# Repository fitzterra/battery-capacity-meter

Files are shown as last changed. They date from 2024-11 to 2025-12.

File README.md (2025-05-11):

Battery Capacity Meter
======================

**Table of Content**

1. [Introduction](#introduction)
2. [Components and software Stack](#components-and-software-stack)
3. [Project Layout](#project-layout)
4. [Firmware Development](#firmware-development)
	1. [Dev environment setup](#dev-environment-setup)
	2. [Flashing MicroPython](#flashing-micropython)
	3. [Submodules](#submodules)
	4. [Building and uploading firmware](#building-and-uploading-firmware)
		1. [Building](#building)
		2. [Uploading](#uploading)
	5. [Building docs](#building-docs)
5. [Documentation](#documentation)

Introduction
------------

This is a project to build something that can measure the capacity of
Lithium-Ion batteries, specifically 18650 cells, but not limited to those.

In order to fairly accurately measure the cell capacity, one has to do a full
discharge of the cell, and measure the energy used during the recharge. Or
alternatively, charge a fully discharged cell, measuring the energy used to get
battery to full capacity.

To get fairly accurate measurements from these techniques are more difficult
that it sounds due to some factors such as:

* Fully charged, or fully discharged are relative states. Unless whatever is
    used to accurately measure fully dis/charged state, there could be large
    variances.
* Unless the dis/charge cycle is done at a very high current rate, it could
    take a long time to fully dis/charge a cell of even a nominal capacity.
* Using large dis/charge currents is not the best way to measure capacity and
    may be more damaging than it needs to be.

To solve this, this meter has these features:

* Allows multiple (up to 4) batteries to be measured independently and
    concurrently.
* Uses known components and calibration to ensure that the fully dis/charged
    states are as close as the same at all times as possible.
* Does not use very large dis/charge currents to do the measurements.
* All dis/charge telemetry are streamed as MQTT data points to allow these to be
    captured in a separate system or database for further analysis - The
    **Battery Capacity Meter UI** project is a UI that evaluates these data
    points and record history and state for a collection of batteries.
* Each battery being measured is given, and expected to have, a unique ID that
    can be used to identify that battery in the telemetry as well as for
    keeping history.
* Allows singe charging, single discharging or full measurement cycles to be
    run per battery.
* A full measurement cycle will first charge the battery fully, then run 2
    (configurable) discharge and then charge cycles.

Components and software Stack
-----------------------------

* ESP32
* Micropython
* ADC ???
* OLED
* Encoder
* TP4056 Breakout
* KiCAD
* Black
* Pylint

Project Layout
--------------

The project contains the hardware sources (schematics, PCB, etc.), firmware
sources, docs, etc. The base structure is:

    ├── doc
    │   ├── design              - Firmware state diagrams, etc.
    │   ├── Electronics         - Schematics, etc in SVG or image format
    │   └── firmware-api        - Firmware auto generated docs - not versioned
    ├── Electronics
    │   └── BatCapMeter         - KiCad project for BC Meter and Controller
    └── Firmware
        ├── ScreenDesign        - Screen design images
        ├── src                 - Firmware source code dir
        │   ├── firmware        - Firmware build dir - not versioned
        │   ├── lib             - Various source libs
        │   ├── micropython_binary - MP binary will be downloaded here - not versioned
        │   ├── pydoctor_templates - Templates for auto HTML api doc building
        │   ├── runtime_conf    - Runtime config before uploading new firmware
        │   ├── testing         - Testing and demos for various libs - NOT testcases
        │   └── ui              - OLED+Rotary Encode UI library
        └── submodules          - All submodules used by the firmware
            ├── micropython-ads1x15
            ├── micropython-mqtt
            ├── micropython-stubs
            ├── micropython-tools
            ├── ssd1306_mp
            ├── ubutton
            └── uencoder

Firmware Development
--------------------

The BCM firmware is in the `Firmware/src` dir and this is the root dir for
development.

There are a number of moving parts to getting the development done, so as much
as possible is set up in a `Makefile` to help with this.

After setting the development environment up (see below), run `make help` to
see what make commands are available.

### Dev environment setup

The development environment also relies on a Python virtual environment to be
available.

The first thing to do is to ensure you set a `venv` up and make sure it is
activated when in the `Firmware/src` dir.

A very easy way to do this is by using [direnv]. This is normally very easy to
install in Linux and MacOS via your package manager or [Homebrew]. An `.envrc`
file for [direnv] is provided in `Firmware/.envrc`. Once you change into this
dir, you will be asked to allow this RC file, and it will set up an Python 3
virtual environment, as well as some other environment variables needed by the
`Makefile`.

You may have to adjust the `DEVICE_PORT` value in this `.envrc` to match the
device your board presents if it is not `/dev/ttyACM0` as the ESP32-S2 does on
Linux. Try `make detect-device` once your environment is set up and the device
is connected - YMMV.

If not using [direnv], make sure you have your own python virtual environment
set up and that the environment variables as in `Firmware/.envrc` are exported
when running any `make` command.

With all this done, run `make dev-env` to install all required Python packages
needed for firmware dev.

### Flashing MicroPython

The Micropython binary to flash to the ESP32 device is defined in the
`MCU_CONF` file.  
Please update this file is required, but this project is built around the Wemos
S2 Mini and all is set up for that device.

The version of the MP binary can be updated though. Look the `MP_DOWNLOAD_SITE`
config value for the download URL. Updated versions may be found there.

In order to get the S2 Mini into flash mode, press and delete both onboard
buttons at the same time. This is needed for all of the binary flash commands
(not needed for firmware flashing as described below).

If this is the first time flashing this device, then the flash first needs to
be erased with `make erase-flash`.

To flash the MP binary, do `make flash-bin`. If the MP binary is not already
downloaded, it will be downloaded from the download URL in the `MCU_CONF` file.

After flashing, reset the device by pressing the reset button.

Now the firmware can be flashed after making sure the submodules are set up.

### Submodules

The firmware uses a number of submodules for various bit of functionality.
These are `git submodules` and you must make sure all submodules have been
cloned. Do this with:

    git submodules sync
    git submodules udate --init

All submodules are cloned as their own repos under `Firmware/submodules`.

I order to include any parts of these submodules in the source, we simply
create symlinks from the submodule to the name we want for it in the source.
For example here are submodules symlinked in the `src/lib` dir:

    ads1x15.py -> ../../submodules/micropython-ads1x15/ads1x15.py
    led.py -> ../../submodules/micropython-tools/led.py
    mqtt_as.py -> ../../submodules/micropython-mqtt/mqtt_as/__init__.py
    ssd1306.py -> ../../submodules/ssd1306_mp/ssd1306.py
    ubutton.py -> ../../submodules/ubutton/ubutton.py
    uencoder.py -> ../../submodules/uencoder/uencoder.py

### Building and uploading firmware

After making sure the submodules are set up as described above, the firmware
can be built and uploaded as described below.

#### Building
This is done with the simple command: `make build`

The way this works is as follows:

* All the Python source files that will make up the final firmware are defined
    in the `MPY_SRC` list in the `Makefile`. If new files are added or others
    removed, this list **MUST** be updated.
* From this list, all source files will first be cross compiled in order to
    speed up runtime.
* As `make` is supposed to do, only changed sources files will be compiled if
    they have not been compiled before.
* All compiled files (`.mpy`) are placed in the `firmware` dir (which will be
    created if it does not exist, and is not versioned), using the same files
    structure as in the `src` dir.
* After this, `firmware` dir is now ready to be uploaded to the device.

#### Uploading

Once the firmware has been built, it can be uploaded.

This is done with `make upload`. Note that the upload target will also first
build any outdated firmware if run directly with having done a `make build`
first.

The firmware allows certain runtime configurations to be made via the OLED +
Encoder UI. These are effectively changes to any default config values and are
then saved in new runtime config files on the device.

In order to make sure **ONLY** the files in the firmware as built will be
placed on the device with the next firmware upload, the upload is a type of
file sync operation where any files not appearing in the built firmware folder,
are deleted from the device, while changed files are uploaded.

This sync operation also makes the uploads faster because only new and changed
compiled files are uploaded.

The problem is with the runtime configs. Since these are not part of the built
firmware, they are also deleted. This is not ideal while developing because
then any runtime config changes needs to be done after every firmware upload.

For this reason the `Makefile` has the `runtime-cfg-backup` target that will
look for any of these runtime config files on the device and copy them to
`runtime_conf/backup`.

The `upload` target has the `runtime-cfg-backup` target as dependency which
will then always first backup any runtime config files before doing the upload
sync. Afterwards, all runtime backups will then be copied back to the device.

To quickly get a REPL after changes were made to any files and an update is
needed, this flow is very useful:

    make upload repl

which will make a new build, backup runtime configs, upload only the changes,
restore runtime config and immediately connect to the device and start the REPL.

### Building docs

The source is extensively documented using Python docstrings. This allows
automatically generating a complete set of source and app documentation using
[pydoctor]

The [pydoctor] main setup is in the `pydoctor.ini` file with some additional
setup in the `docs` target in the `Makefile`.

To build the documentation, run `make docs` - this will show any doc errors,
and build the final static HTML docs in `doc/firmware-api/` from the top level
dir. In this dir will be an `index.html` file that can be opened directly in a
browser.

There is also a CI job for GitLab that will build the docs and make them
available as GitLab pages for the repo. See [Documentation](#Documentation)
below for more.

Documentation
-------------

The application is written in Micropython and the full app docs are available
[here](http://pages.gaul.za/gaulnet/battery-capacity-meter/)

<!-- links -->
[direnv]: https://github.com/direnv/direnv
[Homebrew]: https://brew.sh/
[pydoctor]: https://pydoctor.readthedocs.io

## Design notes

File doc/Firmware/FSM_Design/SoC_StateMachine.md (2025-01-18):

SoC Measure State Machine
=========================

Below is a [state diagram] that governs the [FSM] for measuring SoC for a given
Battery Controller.

```mermaid
---
title: SoC Measurement State Diagram
---

stateDiagram-v2
    direction TB

    classDef error fill:#a44,color:white,font-weight:bold,stroke-width:2px,stroke:#700
    classDef charging fill:#4a4,color:white,font-weight:bold,stroke-width:2px,stroke:#070
    classDef discharging fill:#d50,color:white,font-weight:bold,stroke-width:2px,stroke:#a20
    classDef resting fill:#036,color:white,font-weight:bold,stroke-width:2px,stroke:#059
    classDef canceled fill:#770,color:white,font-weight:bold,stroke-width:2px,stroke:#330
    classDef completed fill:#336,color:white,font-weight:bold,stroke-width:2px,stroke:#559

    %% Possible states and actions to perform when
    %% Transitioning to that state.
    READY: Ready
    CHARGING_1ST: Initial Charge
    note left of CHARGING_1ST
        num_cycles = 0
    end note
    CHARGING: Charging
    REST_CH: Rest post charge
    note right of REST_CH
        num_cycles++
    end note
    DISCHARGING: Discharging
    REST_DCH: Rest post discharge
    COMPLETE: SoC Complete
    CANCEL: SoC Canceled
    ERROR: Error

    class ERROR error
    class CHARGING, CHARGING_1ST charging
    class DISCHARGING discharging
    class REST_CH, REST_DCH resting
    class CANCEL canceled
    class COMPLETE completed

    [*] --> READY

    %% Unexpected Battery Controller state goes to error
    READY --> ERROR: unexpected BC state
    CHARGING_1ST --> ERROR: unexpected BC state
    CHARGING --> ERROR: unexpected BC state
    DISCHARGING --> ERROR: unexpected BC state
    REST_CH --> ERROR: unexpected BC state
    REST_DCH --> ERROR: unexpected BC state

    %% Cancel at any stage
    CHARGING_1ST --> CANCEL: cancel
    CHARGING --> CANCEL: cancel
    DISCHARGING --> CANCEL: cancel
    REST_CH --> CANCEL: cancel
    REST_DCH --> CANCEL: cancel

    %% Manual error reset
    ERROR --> [*]

    %% Start SoC measurement
    READY --> CHARGING_1ST: charge

    %% Rest after 1st charge
    CHARGING_1ST --> REST_CH: charge complete

    %% Starting the cycle

    %% Discharge
    REST_CH --> DISCHARGING: discharge

    %% Fully discharging
    DISCHARGING --> REST_DCH: discharge complete

    %% Charge cycle
    REST_DCH --> CHARGING: charge

    state CycleComplete <<choice>>

    %% Charge complete
    CHARGING --> CycleComplete: charge complete
    CycleComplete -->  REST_CH: num_cycles < max_cycles, charge complete
    CycleComplete -->  COMPLETE: num_cycles == max_cycles, cycle complete

    %% Exit after SoC Complete or Canceled
    COMPLETE --> [*]
    CANCEL --> [*]
```

See the [code] and [api-docs] for more details.

This state diagram was also converted to a [DrawIO] diagram and saved a [PNG].

<!-- Links -->
[state diagram]: https://mermaid.js.org/syntax/stateDiagram.html
[FSM]: https://en.wikipedia.org/wiki/Finite-state_machine
[code]: ./Firmware/src/lib/statemachines.py
[api-docs]: doc/firmware-api/src.lib.bat_controller.StateMachine.html
[DrawIO]: https://app.diagrams.net/
[PNG]: doc/design/SoC_StateMachine.drawio.png
[vim-modeline]: # ( vim: set nofoldenable: )

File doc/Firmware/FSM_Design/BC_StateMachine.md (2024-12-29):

Battery Controller State Machine
================================

Below is a [state diagram] that governs the [FSM] for controlling and monitoring
the Battery Controller.

```mermaid
---
title: Battery Control and Monitor
---

stateDiagram-v2
    direction TB

    classDef yanked fill:#a44,color:white,font-weight:bold,stroke-width:2px,stroke:#700
    classDef charged fill:#4a4,color:white,font-weight:bold,stroke-width:2px,stroke:#070
    classDef discharged fill:#d50,color:white,font-weight:bold,stroke-width:2px,stroke:#a20
    classDef paused fill:#660,color:white,font-weight:bold,stroke-width:2px,stroke:#880
    classDef currentflow fill:#036,color:white,font-weight:bold,stroke-width:2px,stroke:#059
    classDef ready fill:#336,color:white,font-weight:bold,stroke-width:2px,stroke:#559
    
    %% Possible states and actions to perform when
    %% Transitioning to that state.
    DISABLED: Disabled
    note right of DISABLED
        Monitors disabled
        Ch and Dch Off
    end note
    NOBAT: No Battery
    note right of NOBAT
        Ch and Dch Stop
        Reset Bat ID
    end note
    BAT_NOID: Battery, No ID
    note right of BAT_NOID
        Gen Bat ID
    end note
    GET_ID: Input Bat ID
    BAT_ID: Battery + ID
    note right of BAT_ID
        Reset monitors
    end note
    CHARGE: Charging
    note left of CHARGE
        Ch Start
    end note
    CHARGE_PAUSE: Charging Paused
    note left of CHARGE_PAUSE
        Ch Stop
    end note
    CHARGED: Charge completed
    note right of CHARGED
        Ch Stop
    end note
    DISCHARGE: Discharging
    note left of DISCHARGE
        Dch Sart
    end note
    DISCHARGE_PAUSE: Disharging Paused
    note left of DISCHARGE_PAUSE
        Dch Stop
    end note
    DISCHARGED: Disharge Completed
    note right of DISCHARGED
        V_Mon Reset
        Dch Stop
    end note
    YANKED: Battery removed
    note left of YANKED
        Ch and Dch Stop
    end note

    class BAT_ID ready
    class YANKED yanked
    class CHARGED charged
    class DISCHARGED discharged
    class CHARGE, DISCHARGE currentflow
    class DISCHARGE_PAUSE, CHARGE_PAUSE paused

    %% Possible events
    %% disable: Sets the FSM to disabled
    %% init: Initialises the FSM to the initial state
    %% v_jump: > +2V change in battery voltage in 300ms
    %% v_drop: > -2V change in battery voltage in 500ms (this rate is slower)
    %% ch_jump: > +200mA change in charge current in 100ms
    %% ch_drop: > -200mA change in charge current in 100ms
    %% dch_jump: > +200mA change in discharge current in 100ms
    %% dch_drop: > -200mA change in discharge current in 100ms
    %% ch_done: ?? Not sure how to know charge is completed yet
    %% dch_done: ?? Not sure how to know discharge is completed yet
    %% charge: Start charge by switching on the MOSFET switched on
    %% discharge: Start discharge by switching on the MOSFET switched on
    %% pause: Pause charging or discharging. Turn off MOSFET
    %% resume: Resume charging or discharging. Turn on MOSFET
    %% reset: Resets monitor after yank
    %% get_id: Event to indicate weare getting user input for the ID
    %% set_id: ID input complete and battery ID has been set.
    %% reset_metrics: Resets the metrics for a battery after halting charge/dischare

    %% If ANY input ADCs are not available we are disabled with nowhere
    %% to transition to
    [*] --> DISABLED: disable

    %% Start off assuming we have no battery installed
    [*] --> NOBAT: init

    %% Battery inserted
    NOBAT --> BAT_NOID: v_jump
    %% Battery removed while in BAT_NOID
    BAT_NOID --> YANKED: v_drop

    %% Getting the battery ID
    BAT_NOID --> GET_ID: get_id
    %% Yank while getting the ID
    GET_ID --> YANKED: v_drop

    %% Set ID from user input
    GET_ID --> BAT_ID: set_id
    %% Yank
    BAT_ID --> YANKED: v_drop

    %% Start Charging
    BAT_ID --> CHARGE: charge
    %% Yank
    CHARGE --> YANKED: ch_drop

    %% Pausing the charge
    CHARGE --> CHARGE_PAUSE: pause
    %% Continue charging
    CHARGE_PAUSE --> CHARGE: resume
    %% Reset metrics
    CHARGE_PAUSE --> BAT_ID: reset_metrics
    %% Yank
    CHARGE_PAUSE --> YANKED: v_drop

    %% Charge complete
    CHARGE --> CHARGED: ch_done
    %% Yank
    CHARGED --> YANKED: v_drop
    %% Reset metrics
    CHARGED --> BAT_ID: reset_metrics

    %% Start Discharging
    BAT_ID --> DISCHARGE: discharge
    %% Yank
    DISCHARGE --> YANKED: dch_drop
    
    %% Pausing the discharge
    DISCHARGE --> DISCHARGE_PAUSE: pause
    %% Continue discharging
    DISCHARGE_PAUSE --> DISCHARGE: resume
    %% Reset metrics
    DISCHARGE_PAUSE --> BAT_ID: reset_metrics
    %% Yank
    DISCHARGE_PAUSE --> YANKED: v_drop

    %% Discharge complete
    DISCHARGE --> DISCHARGED: dch_done
    %% Yank
    DISCHARGED --> YANKED: v_drop
    %% Reset metrics
    DISCHARGED --> BAT_ID: reset_metrics

    %% Reset after yank
    YANKED --> NOBAT: reset

    %% Auto reset from yanked if battery is inserted again
    YANKED --> BAT_NOID: v_jump
```

See the [code] and [api-docs] for more details.

This state diagram was also converted to a [DrawIO] diagram and saved a [PNG].

<!-- Links -->
[state diagram]: https://mermaid.js.org/syntax/stateDiagram.html
[FSM]: https://en.wikipedia.org/wiki/Finite-state_machine
[code]: ./Firmware/src/lib/bat_controller.py
[api-docs]: doc/firmware-api/src.lib.bat_controller.StateMachine.html
[DrawIO]: https://app.diagrams.net/
[PNG]: doc/design/BC_StateMachine.drawio.png
[vim-modeline]: # ( vim: set nofoldenable: )

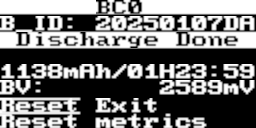
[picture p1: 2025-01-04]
doc/Firmware/Screen_Design/OLED128x64_Disharge_Complete_larger.png

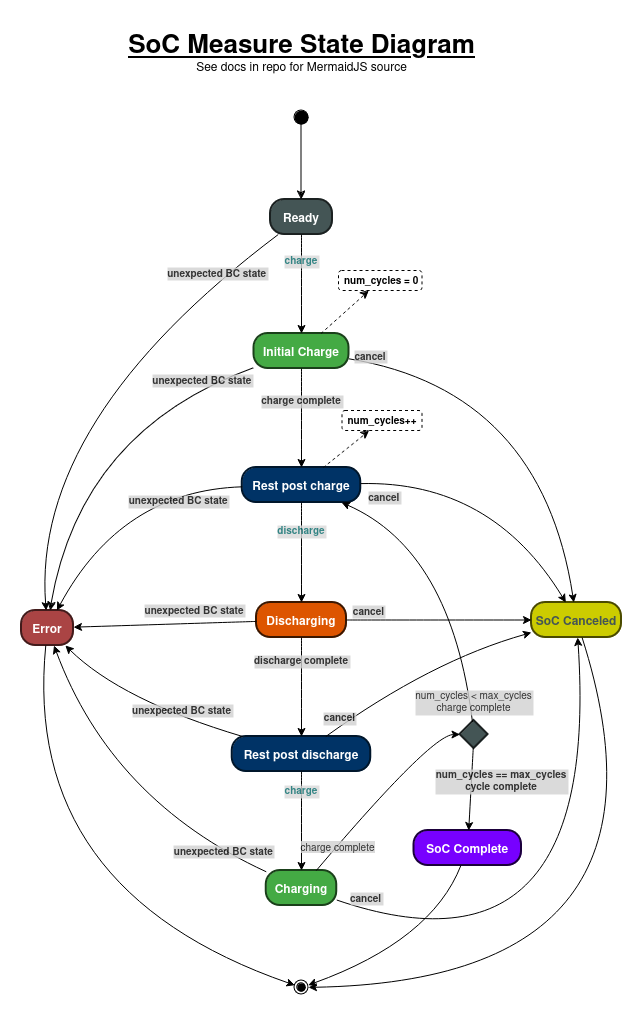
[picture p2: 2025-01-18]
doc/Firmware/FSM_Design/SoC_StateDiagram.drawio.png

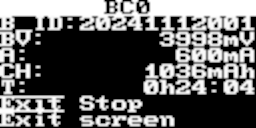
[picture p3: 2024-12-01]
doc/Firmware/Screen_Design/OLED128x64_Charge_State_large.gif

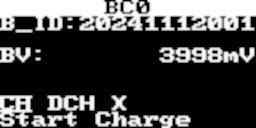
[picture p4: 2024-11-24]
doc/Firmware/Screen_Design/OLED128x64_BatIns_State_larger.gif

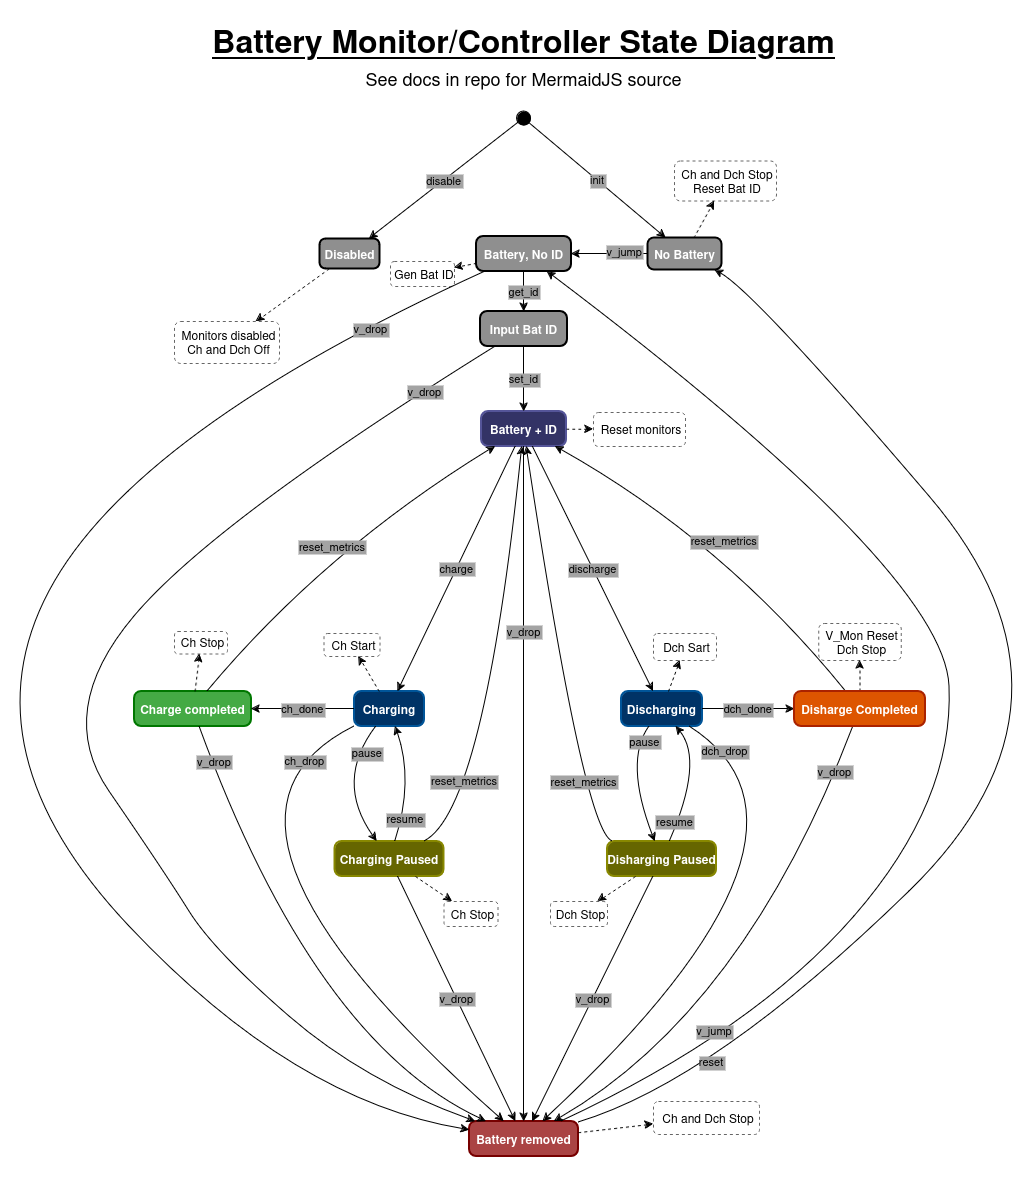
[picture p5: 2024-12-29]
doc/Firmware/FSM_Design/BC_StateDiagram.drawio.png

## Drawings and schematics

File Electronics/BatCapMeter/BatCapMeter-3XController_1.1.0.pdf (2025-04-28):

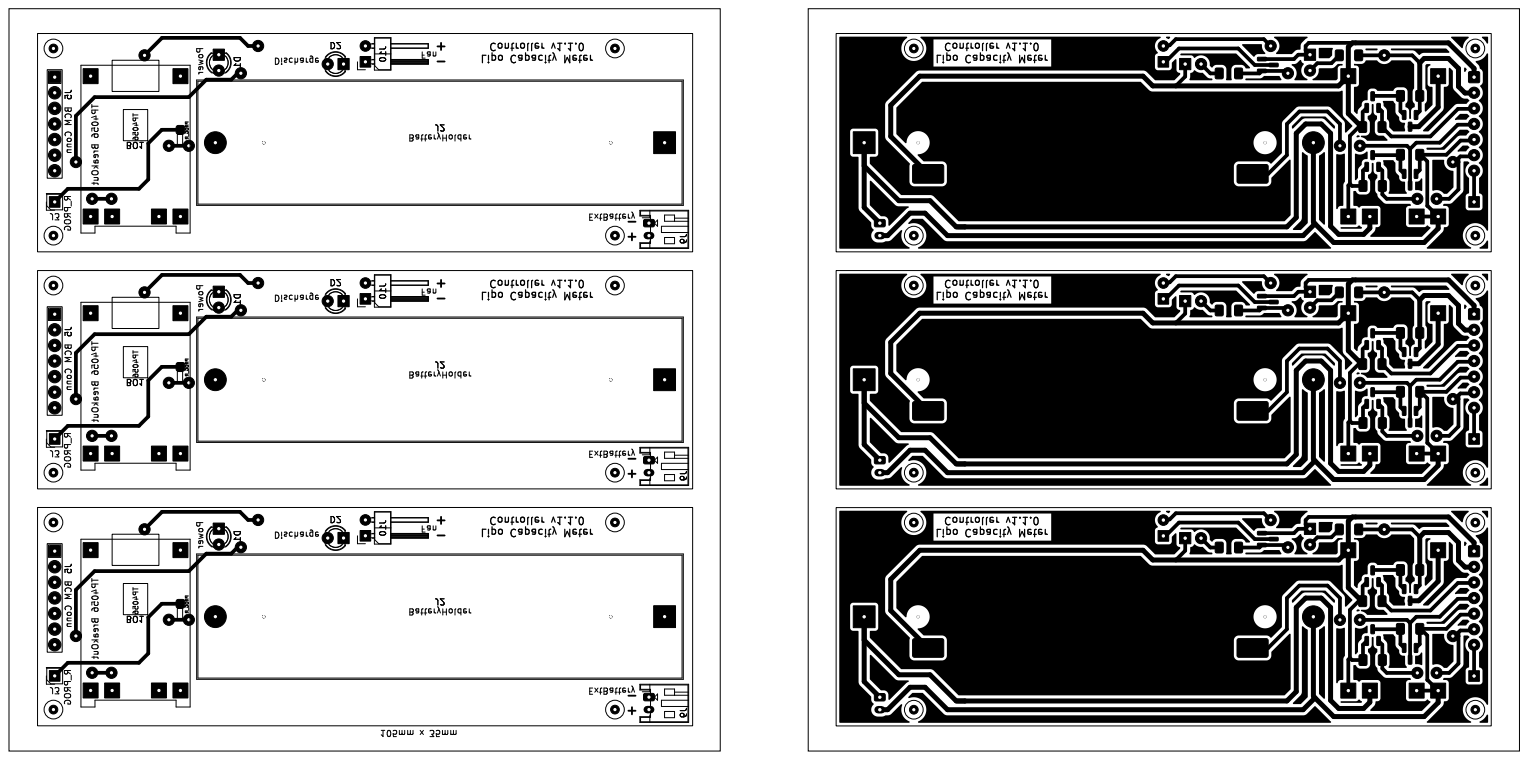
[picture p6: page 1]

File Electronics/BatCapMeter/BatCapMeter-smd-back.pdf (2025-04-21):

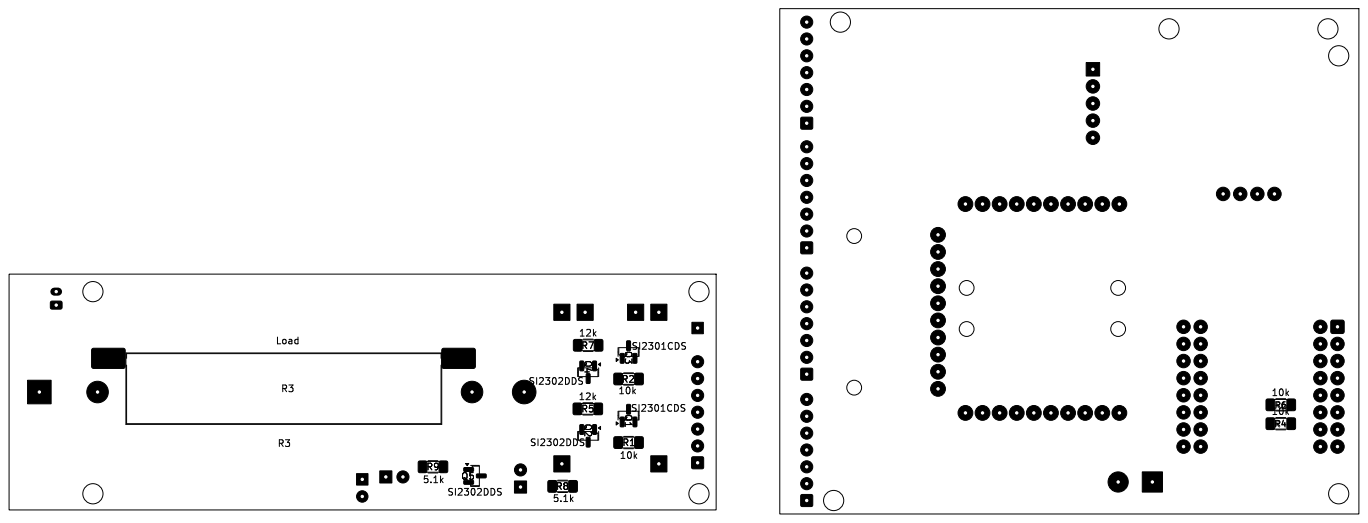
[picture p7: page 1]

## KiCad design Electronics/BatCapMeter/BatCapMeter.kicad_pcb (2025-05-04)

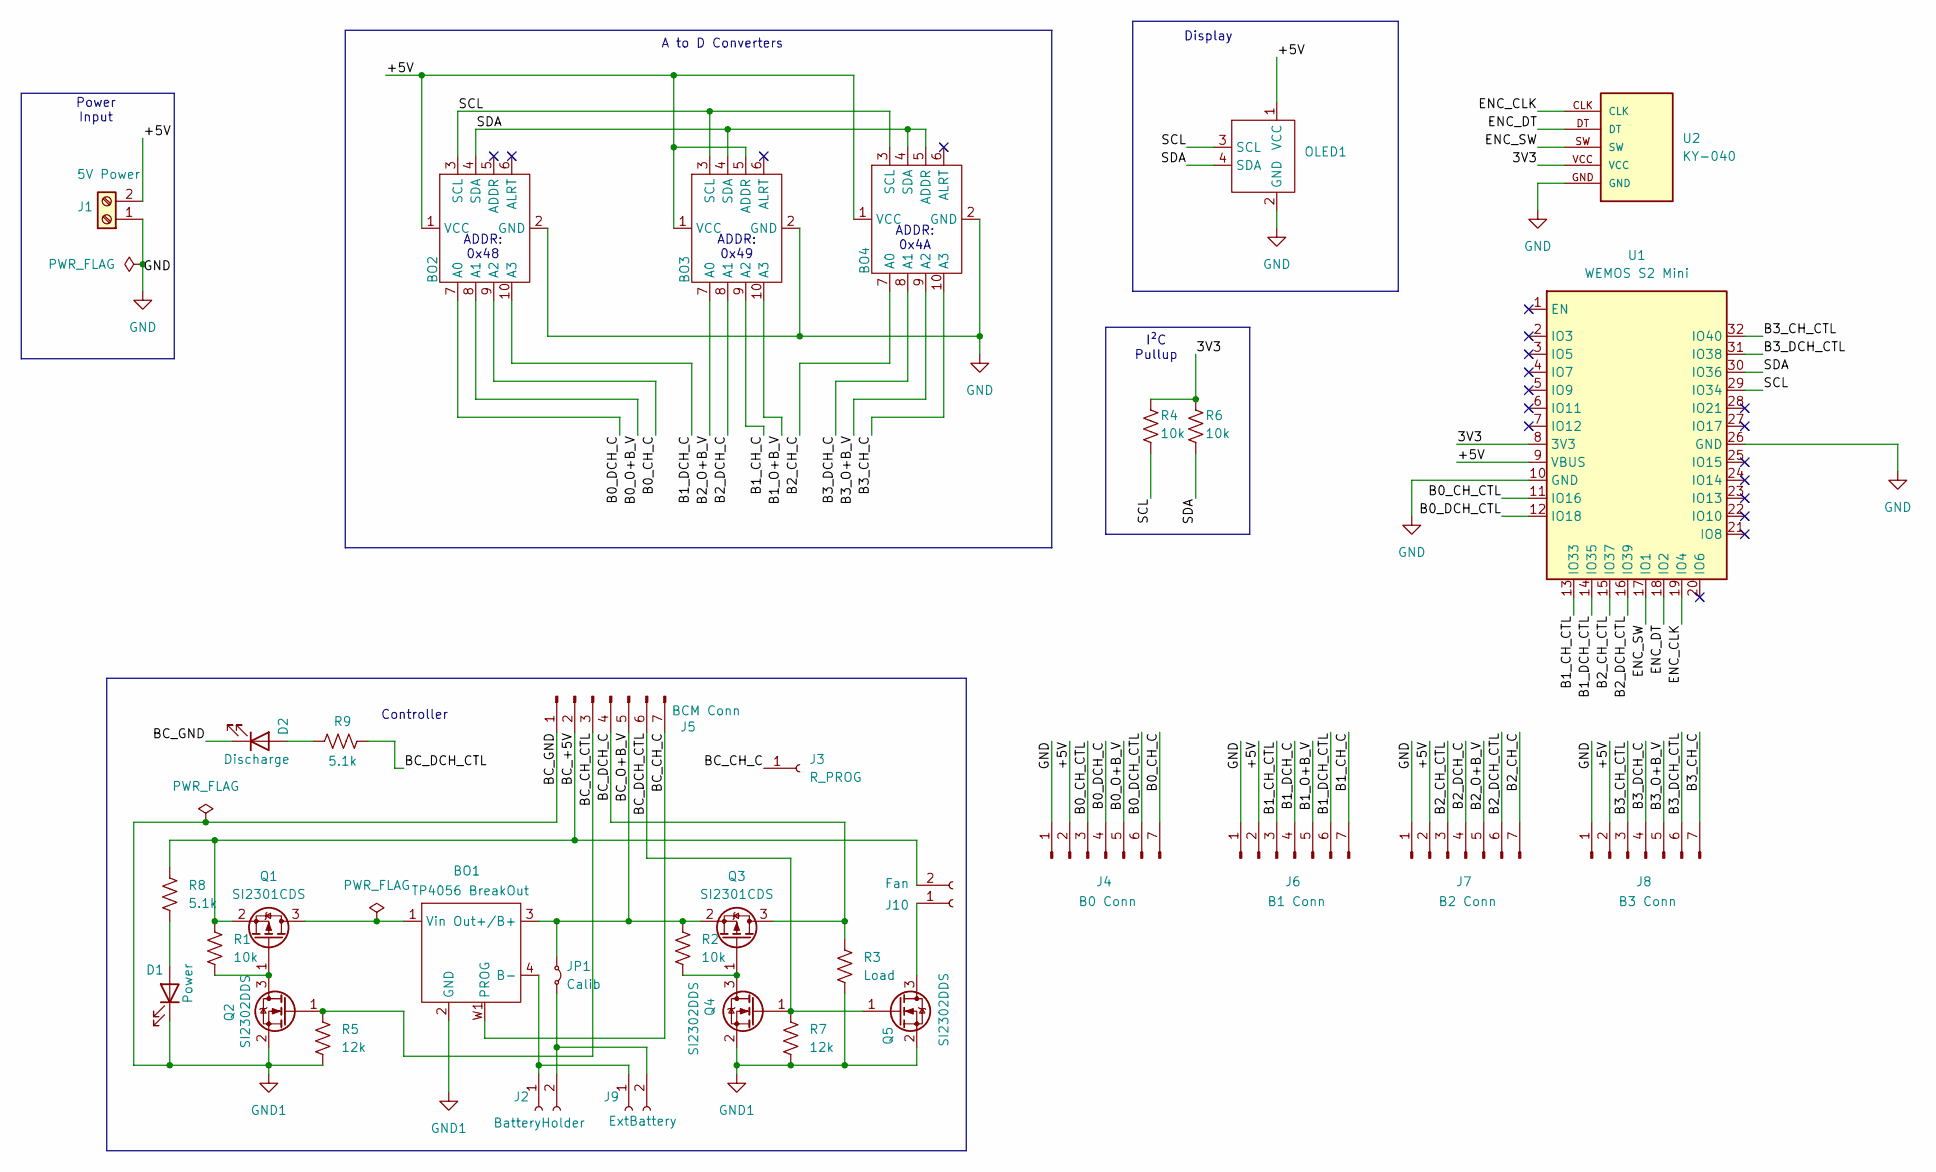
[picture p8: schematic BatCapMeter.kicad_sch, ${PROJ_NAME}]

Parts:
BO1: TP4056 BreakOut; TP4056_BreakOut_2
BO2, BO3, BO4: ADS1115_BO
D1: Power; LED_D3.0mm_Clear
D2: Discharge; LED_D3.0mm_Clear
J1: 5V Power; TerminalBlock_bornier-2_P5.08mm
J2: BatteryHolder; BatteryHolder_MPD_BH-18650-PC2
J3: R_PROG; PinHeader_1x01_P2.54mm_Vertical
J4: B0 Conn; SolderWire-1x07_P2.5mm_D0.8mm_OD1.8mm
J5: BCM Conn; SolderWire-1x07_P2.5mm_D0.8mm_OD1.8mm
J6: B1 Conn; SolderWire-1x07_P2.5mm_D0.8mm_OD1.8mm
J7: B2 Conn; SolderWire-1x07_P2.5mm_D0.8mm_OD1.8mm
J8: B3 Conn; SolderWire-1x07_P2.5mm_D0.8mm_OD1.8mm
J9: ExtBattery; JST_PH_S2B-PH-K_1x02_P2.00mm_Horizontal
J10: Fan; PinHeader_1x02_P2.54mm_Horizontal
JP1: Calib; PinHeader_1x02_P2.54mm_Vertical
OLED1: SSD13306_OLED_128x64-2_NonPad_Mounting_Holes
Q1, Q3: SI2301CDS; SOT-23
Q2, Q4, Q5: SI2302DDS; SOT-23
R1, R2, R4, R6: 10k; R_1206_3216Metric_Pad1.30x1.75mm_HandSolder
R3: Load; R_Axial_Power_L47.0mm_W10.0mm_P48.0mm_SMD
R5, R7: 12k; R_1206_3216Metric_Pad1.30x1.75mm_HandSolder
R8, R9: 5.1k; R_1206_3216Metric_Pad1.30x1.75mm_HandSolder
U1: WEMOS S2 Mini; WEMOS_S2_mini_NoKeepOut
U2: KY-040; KY-040-PORT

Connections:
/3V3: R4.1, R6.1, U1.8 (3V3), U2.VCC
/B0_CH_C: BO2.9 (A2), J4.7
/B0_CH_CTL: J4.3, U1.11 (IO16)
/B0_DCH_C: BO2.7 (A0), J4.4
/B0_DCH_CTL: J4.6, U1.12 (IO18)
/B0_O+B_V: BO2.8 (A1), J4.5
/B1_CH_C: BO3.9 (A2), J6.7
/B1_CH_CTL: J6.3, U1.13 (IO33)
/B1_DCH_C: BO2.10 (A3), J6.4
/B1_DCH_CTL: J6.6, U1.14 (IO35)
/B1_O+B_V: BO3.10 (A3), J6.5
/B2_CH_C: BO4.7 (A0), J7.7
/B2_CH_CTL: J7.3, U1.15 (IO37)
/B2_DCH_C: BO3.8 (A1), J7.4
/B2_DCH_CTL: J7.6, U1.16 (IO39)
/B2_O+B_V: BO3.7 (A0), J7.5
/B3_CH_C: BO4.10 (A3), J8.7
/B3_CH_CTL: J8.3, U1.32 (IO40)
/B3_DCH_C: BO4.8 (A1), J8.4
/B3_DCH_CTL: J8.6, U1.31 (IO38)
/B3_O+B_V: BO4.9 (A2), J8.5
/BC_+5V: J5.2, J10.2, Q1.2 (S), R1.1, R8.1
/BC_CH_C: BO1.W1 (PROG), J3.1, J5.7
/BC_CH_CTL: J5.3, Q2.1 (G), R5.1
/BC_DCH_C: J5.4, Q3.3 (D), R3.1
/BC_DCH_CTL: J5.6, Q4.1 (G), Q5.1 (G), R7.1, R9.1
/BC_O+B_V: BO1.3 (Out+/B+), J5.5, JP1.1 (A), Q3.2 (S), R2.1
/ENC_CLK: U1.19 (IO4), U2.CLK
/ENC_DT: U1.18 (IO2), U2.DT
/ENC_SW: U1.17 (IO1), U2.SW
/SCL: BO2.3 (SCL), BO3.3 (SCL), BO4.3 (SCL), OLED1.3 (SCL), R4.2, U1.29 (IO34)
/SDA: BO2.4 (SDA), BO3.4 (SDA), BO4.4 (SDA), BO4.5 (ADDR), OLED1.4 (SDA), R6.2, U1.30 (IO36)
GND1: BO1.2 (GND), D1.1 (K), D2.1 (K), J5.1, Q2.2 (S), Q4.2 (S), Q5.2 (S), R3.2, R5.2, R7.2
unnamed: BO1.4 (B-), J2.1, J9.1
unnamed: BO1.1 (Vin), Q1.3 (D)
unnamed: D1.2 (A), R8.2
unnamed: D2.2 (A), R9.2
unnamed: J2.2, J9.2, JP1.2 (B)
unnamed: J10.1, Q5.3 (D)
unnamed: Q1.1 (G), Q2.3 (D), R1.2
unnamed: Q3.1 (G), Q4.3 (D), R2.2

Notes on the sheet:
Power Input
I²C Pullup
Display
ADDR: 0x48
ADDR: 0x4A
Controller
ADDR: 0x49
A to D Converters

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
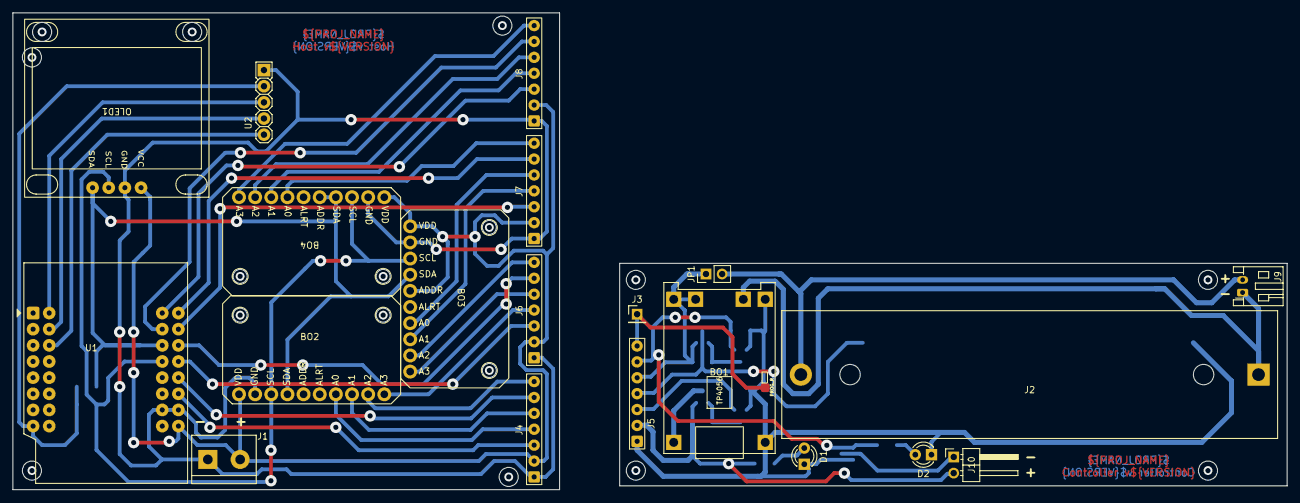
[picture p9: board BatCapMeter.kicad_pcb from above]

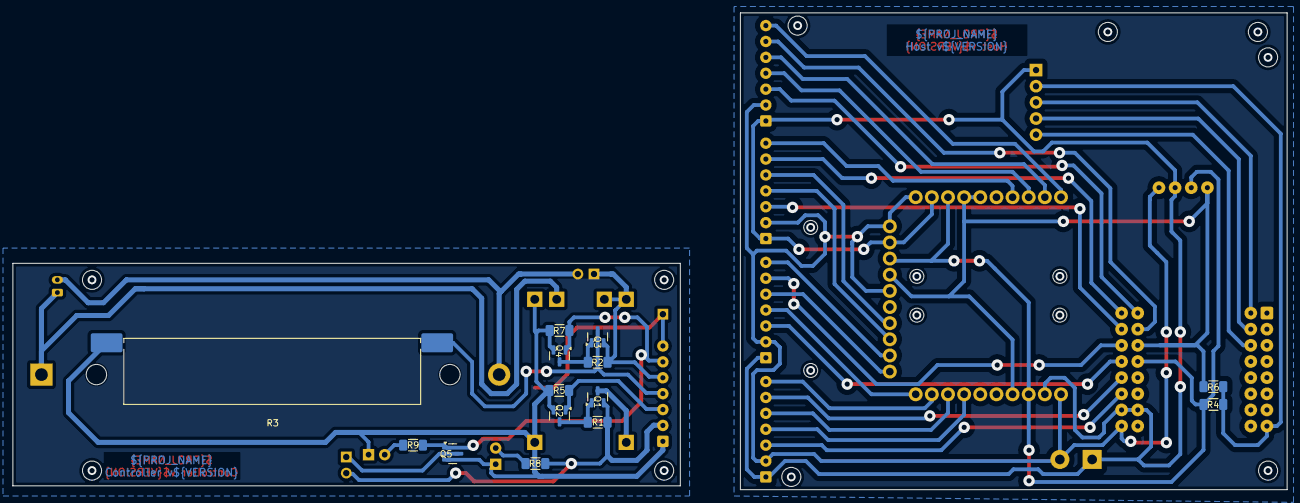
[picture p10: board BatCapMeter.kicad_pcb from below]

Board: 2 copper layers, 200.4 x 75.0 mm, 34 parts (14 on the bottom side), 43 nets.

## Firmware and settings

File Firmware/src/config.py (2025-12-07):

"""
Project configuration module.

This module is responsible for defining the config to match the hardware_.

The `hardware config`_ section defines the various hardware configs based on
the `schematic`_, which are then encoded in the `HARDWARE_CFG` structure.

The controller config elements in this structure can then be used to
instantiate `BatteryController` instances which are the low level control and
monitor interfaces to the hardware.

Besides the hardware_ config, there are also other runtime config values. All
configs are usually static and baked into the firmware, but the
`sitelocal_conf` module provides functionality to override these config values
and maintain the updated configs across restarts in the running system.

The `RUNTIME_CONF` in the `screens` module provides a UI config screen where
many of these values can be overridden, for example.

Attributes:
    PIN_LED: Onboard LED pin. Default for S2 Mini

    ADC_GAIN: This is the gain to set for the builtin ADS1115_ PGA.

        We will be measuring Lithium cells, so we can go up to 4.2V, which
        means we need to use the larges Full Scale Reading (FSR) which is
        ±6.144V or a granularity of 187.5µV per value.  The ads1x15 lib uses a
        gain mapping where the first entry (0) is the one we need for the gain
        we require.

        Note:
            We use the same gain for voltage and current/charge monitors. This
            needs some more investigation to see if the current/charge monitors
            may need a different GAIN scale.

    ADC_SAMPLE_RATE: The number of ADC samples any monitor should take per
        second.

        This will be the ``rate`` arg for `VoltageMonitor` and `ChargeMonitor`
        instances for each `BatteryController` set up. Each one of these
        monitors can be queried to see how long they take to complete an
        ADC sample by looking at the `ADCMonitor._tm_adc_sample` variable.

        The higher this value, the more samples are taken and possibly
        increased accuracy, but the less time is left over for other asyncio
        tasks. For what this application does, 2 samples per second should be
        plenty, and the only negative side effect will be that spikes will not
        be detected too quickly (battery inserts and yanks)


    OLED_ADDR: I²C address for SSD1306 OLED

    OLED_W: OLED width in pixels

    OLED_H: OLED height in pixels

    ENC_CLK: GPIO for encoder ``clk`` pin.

    ENC_DT: GPIO for encoder ``data`` pin.

    ENC_SW: GPIO for encoder ``switch`` pin. Will enable internal pull up for
        this pin.

    LOAD_R: The value to use for all battery controller load resistors.

        This is the resistor used for discharge measurement. Currently all
        battery controllers are expected to use the same load resistor value.
        The unit is ohm (Ω).

    HARDWARE_CFG: Complete hardware config for all available battery
        controllers supported by the hardware.

        This is a list of configs per battery controller as defined in the
        `Hardware config`_ section.

        Each list entry is a 4 element tuple as follows:

        .. python::

            (
                "BC0",     # Controller friendly name
                (          # Battery voltage monitor config
                    0x48,  #   ADC Address
                    1,     #   ADC Channel
                    None   # Averaging window if not None
                           # See ``avg_w`` arg to `VoltageMonitor.__init__`
                ),
                (          # Charge control and monitor on TP4056
                    16,    #   IO pin to enable charging
                    0x48,  #   ADC Address
                    2,     #   ADC Channel
                    1,     #   Shunt resistor value
                           #   See "ADC Inputs per battery controller" in module doc
                    None   # Averaging window if not None
                           # See ``avg_w`` arg to `ChargeMonitor.__init__`
                ),
                (          # Discharge control and monitor
                    18,    #   IO pin to enable discharging
                    0x48,  #   ADC Address
                    0,     #   ADC Channel
                    LOAD_R,#   Shunt resistor value
                    None   # Averaging window if not None
                           # See ``avg_w`` arg to `ChargeMonitor.__init__`
                )
            )

    LOGGING_CFG: Used to disable logging per named logger.

        By default logging is enabled for all log requests (barring the level
        allows it), but this config allows specific loggers to be disabled per
        destination. See `lib.ulogging.LOGGING_CFG` for more details and info
        about destinations.

        For effective use of this mechanism, it would be best to set up a
        logger per module via `getLogger` ``(__name__)`` and then the module name
        can be used as the logger name in this structure.

        Then, for the module/logger name, the standard logging or telemetry
        logging can be disabled/enabled by the destination keys as explained in
        `lib.ulogging.LOGGING_CFG`.

    ads1115: An ADS1115 instance set to the default I²C address, available for
        all monitors to use.

        This is used in `VoltageMonitor` and `ChargeMonitor` configs for the
        battery controllers. These controllers will set the address up as they
        need to when reading the specific ADS1115 modules/channels as needed.

    V_SPIKE_TH: Voltage spike threshold in mV.

        If a change in battery voltage (up or down) greater than this threshold is
        detected for a period less than `V_SPIKE_TH_T`, a voltage spike event
        is triggered.

        See:
            `SpikeDetectCFG`

    V_SPIKE_TH_T: Voltage spike detection threshold time in ms.

        This is the max time allowed for a voltage change greater than
        `V_SPIKE_TH` to trigger a voltage spike event.

        For a quick change in voltage, the event will be triggered immediately,
        but when removing a battery, the smoothing caps over the battery takes
        time to discharge, so the voltage change takes longer.

        This time value should be greater than the time it takes for a
        `V_SPIKE_TH` change to occur while discharging these caps.

        See:
            `SpikeDetectCFG`

    C_SPIKE_TH: Charge current spike threshold in mA.

        Any charge current change greater than this threshold value (up or
        down), occurring within a period less than `C_SPIKE_TH_T`, will cause a
        charge spike event to be triggered.

        See:
            `SpikeDetectCFG`

    C_SPIKE_TH_T: Charge current spike detection threshold time in ms.

        This is the max time allowed for a charge current change greater than
        `C_SPIKE_TH` to trigger a charge current spike event.

        See:
            `SpikeDetectCFG`

    D_SPIKE_TH: Discharge current spike threshold in mA.

        Any discharge current change greater than this threshold value (up or
        down), occurring within a period less than `D_SPIKE_TH_T`, will cause a
        discharge spike event to be triggered.

        Important:
            This value is used to detect when discharge is completed. Full
            discharge is reached when the DW01_ chips detects the battery
            voltage to be around 2.4V. When this voltage is reached,
            discharging stops and the discharge current drops to zero.

            In order for this to be detected, this threshold should be less
            than the final current still flowing when the battery discharged
            threshold voltage (2.4V) is reached. Thus this value should be less
            than ``2.4 / LOAD_R``.

        See:
            `SpikeDetectCFG`

    D_SPIKE_TH_T: Discharge current spike detection threshold time in ms.

        This is the max time allowed for a discharge current change greater
        than `D_SPIKE_TH` to trigger a discharge current spike event.

        See:
            `SpikeDetectCFG`

    C_VOLTAGE_TH: The battery threshold voltage at which we determine full
        charge to be completed in mV.

        This voltage is not used directly, but rather, when 
        `BatteryController._chargeSpike` detects a current spike, and the last battery
        voltage is above this threshold, then we generate fully charged event.

    D_VOLTAGE_TH: The battery threshold voltage at which we determine full
        discharge to be completed in mV.

        This voltage is not used directly, but rather, when a
        `BatteryController._dischargeSpike` is detected, and the last battery
        voltage is below this threshold, then we generate fully discharged
        event.

    D_V_RECOVER_TH: The voltage the battery needs to return to after discharge
        before we deem it recovered from discharge.
    
        The DW01 has this set to between 2.9V and 3.1V as a guide.

    D_RECOVER_MAX_TM: The max time we will allow for recovery after a discharge.

        If the recovery conditions are not met in this period, we will assume
        the battery is not a good state.

    D_RECOVER_TEMP: Once we bring in temperature measurement, this will be the
        recovery temp we expect the battery to be at.

    D_RECOVER_MIN_TM: Since we do not have battery temperature measurement
        currently, we will use a min rest time instead. This must be less than
        D_RECOVER_TM

    TELEMETRY_EMIT_FREQ: For continues telemetry emission states like charging
        and discharging, this is the frequency (in milliseconds) with which to
        emit telemetry updates.

    SOC_REST_TIME: The amount of time to rest after a charge or discharge
        complete to allow the battery and/or load temperatures to stabilize.

    SOC_NUM_CYCLES: The number of cycles to run for a SoC measurement

    CALIB_STEP: The step value to increase or decrease a shunt resistor value
       by when calibrating the shunt, via the `Calibration` UI screen.

    SCRN_OFF_TM: The time in seconds without any user input when the screen
        saver will be activated. Can also be set from the UI config menu.

.. _ADS1115: https://components101.com/modules/ads1115-module-with-programmable-gain-amplifier
.. _DW01: https://www.best-microcontroller-projects.com/support-files/dw01a.pdf
.. _hardware: index.html#rst-hardware
.. _hardware config: index.html#rst-hardware-config
.. _schematic: index.html#rst-schematic
"""

from i2c_config import const, i2c

from lib.ads1x15 import ADS1115

from shunt_conf import (
    BC0_CH_R,
    BC1_CH_R,
    BC2_CH_R,
    BC3_CH_R,
    BC0_DCH_R,
    BC1_DCH_R,
    BC2_DCH_R,
    BC3_DCH_R,
)

from sitelocal_conf import overrideLocal

# Pins used on the S2 Mini. See docstring Attributes for more.
PIN_LED = 15

# See docstring Attributes for more.
ADC_GAIN: int = const(0)

# See docstring Attributes for more.
ads1115 = ADS1115(i2c, gain=ADC_GAIN)

# See docstring Attributes for more.
ADC_SAMPLE_RATE = 3

# OLED. See docstring Attributes for more.
OLED_ADDR = 0x3C
OLED_W = const(128)
OLED_H = const(64)

# Encoder pins. See docstring Attributes for more.
ENC_CLK = const(4)
ENC_DT = const(2)
ENC_SW = const(1)

# Load resistor
LOAD_R = 8


# Config for all battery controllers
HARDWARE_CFG = [
    (
        "BC0",
        (0x48, 1, 5),
        (16, 0x48, 2, BC0_CH_R, None),
        (18, 0x48, 0, BC0_DCH_R, None),
    ),
    (
        "BC1",
        (0x49, 3, 5),
        (33, 0x49, 2, BC1_CH_R, None),
        (35, 0x48, 3, BC1_DCH_R, None),
    ),
    (
        "BC2",
        (0x49, 0, 5),
        (37, 0x4A, 0, BC2_CH_R, None),
        (39, 0x49, 1, BC2_DCH_R, None),
    ),
    (
        "BC3",
        (0x4A, 2, 5),
        (40, 0x4A, 3, BC3_CH_R, None),
        (38, 0x4A, 1, BC3_DCH_R, None),
    ),
]

# Default spike detection thresholds and times for voltage spike detection.
V_SPIKE_TH = 600  # Threshold for detecting voltage spikes
# Max time for this change to happen - removing a battery has a slow ramp down
# to 0V
V_SPIKE_TH_T = 1000

# Default spike detection thresholds and times for charge current spike detection.
C_SPIKE_TH = 100
# Max time for this change to happen
C_SPIKE_TH_T = 600

# Default spike detection thresholds and times for discharge current spike detection.
D_SPIKE_TH = 100
# Max time for this change to happen
D_SPIKE_TH_T = 600

# The battery voltage threshold at which we determine that charge is
# completed.
C_VOLTAGE_TH = 4180
## Discharge thresholds
# The battery voltage threshold at which we determine that discharge is
# completed. This should be above the DW01 over-discharge threshold of between
# 2.3V and 2.5V in order to not have the DW01 disconnect the battery. Keep in
# mind that id the Voltage monitor has an averaging window set, that the
# averaging may be lagging the voltage that the DW01 sees.
D_VOLTAGE_TH = 2600
# The voltage the battery needs to return to after discharge before we deem it
# recovered from discharge. The DW01 has this set to between 2.9V and 3.1V as a
# guide.
D_V_RECOVER_TH = 2900
# The max time we will allow for recovery after a discharge. If the recovery
# conditions are not met in this period, we will assume the battery is not a
# good state.
D_RECOVER_MAX_TM = 7 * 60
# Once we bring in temperature measurement, this will be the recovery temp we
# expect the battery to be at.
D_RECOVER_TEMP = 40
# Since we do not have battery temperature measurement currently, we will use a
# min rest time instead. This must be less than D_RECOVER_TM
D_RECOVER_MIN_TM = 3 * 60

##### Telemetry config #####
# For continues telemetry emission states like charging and discharging, this is
# the frequency (in milliseconds) with which to emit telemetry updates.
TELEMETRY_EMIT_FREQ = 5000

##### SoC Measurement config ####
# The amount of time to rest after a charge or discharge complete to allow the
# battery and/or load temperatures to stabilize.
SOC_REST_TIME = 5 * 60

# The number of cycles to run for a SoC measurement
SOC_NUM_CYCLES = 2

##### Calibration config ######
# The step value to increase or decrease a shunt resistor value by when
# calibrating the shunt.
CALIB_STEP = 0.05

#### UI Config #####
# How long to wait before switching the display off to save the screen. In
# seconds.
SCRN_OFF_TM = 30

#### Watchdog module config ######
# If we should log memory usage stats or not.
WD_LOG_MEM = True

##### Logging config #####
LOGGING_CFG = {
    "__main__": {
        "log": True,
        "telem": False,
    },
    "watchdog": {
        "log": True,
        "telem": True,
    },
    "screens": {
        "log": True,
        "telem": False,
    },
    "telemetry": {
        "log": True,
        # If True, it causes recursive telemetry logging. Keep it False
        "telem": False,
    },
}

# Override any site local values
overrideLocal(__name__, locals())

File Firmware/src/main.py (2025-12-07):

"""
Main entry point for for `BatteryController`.

"""

import sys
import uasyncio as asyncio
from config import HARDWARE_CFG
from lib.bat_controller import BatteryController
from lib.utils import stdinKeyMonitor
from lib.ulogging import getLogger
from watchdog import watchdog
import net_conn
from telemetry import mqManager, broadcast

from screens import uiSetup

logger = getLogger(__name__)


def asyncIOExeption(loop, context):
    """
    Global Asyncio exception handler.
    """
    print("Global handler")
    sys.print_exception(context["exception"])  # pylint: disable=no-member
    loop.stop()
    sys.exit()  # Drastic - loop.stop() does not work when used this way


class BCSerialUI:
    """
    A UI for the `BatteryController` over the serial interface.

    This UI allows monitoring and controlling the `BatteryController` from a
    connected computer of USB or serial interface.

    This type of interface is very limited since full control over the
    connected terminal screen is too complex for what this UI is meant for.

    All we do here (for now) is output the current BC status and allow keyboard
    input to control things like starting, pausing, resuming charging and
    discharging etc.

    The display will be a continuous scrolling display of the current status.
    The ``?`` key will show a menu of available keys.
    """

    def __init__(self, bcs: list(BatteryController)):
        """
        Instance initializer.

        Args:
            bcs: A list of `BatteryController` instances.
        """
        # We need at least one
        if not bcs:
            logger.error(
                "%s: At least one BatteryController needed. Aborting.",
                self.__class__.__name__,
            )
            return

        # List of BCs
        self.bcs = bcs
        # Index into bcs of the current active BC
        self.active_bc = 0
        # A shortcut to self.bcs[self.active_bc] - set by setActive
        self.bc = None

        # If True, the output will be paused
        self.pause = False

        self.setActive(0)

        # Start the status monitor task
        asyncio.create_task(self.statusMonitor())
        # And the key monitor will key input call back to keyInput
        asyncio.create_task(stdinKeyMonitor({"_default_": (self.keyInput,)}, logger))

    def setActive(self, idx: int):
        """
        Sets the active BC to monitor from index supplied.

        Args:
            idx: Index into `bcs` for the BC to make active.
        """
        if not 0 <= idx < len(self.bcs):
            logger.error(
                "%s : Invalid BC index to make active: %s", self.__class__.__name__, idx
            )
            return

        self.active_bc = idx
        # Set the active BC shortcut
        self.bc = self.bcs[self.active_bc]
        self.output("\nSwitching to BC: %s\n", self.bc)

    def output(self, msg: str, *args: tuple, end="\n"):
        """
        Prints the message and to stdout.

        Args:
            msg: A string with optional % formatting options as for logging.
            args: Arguments for all % formatting options in ``msg``
        """
        print(msg % args, end=end)

    def keyInput(self, ch):
        """
        Callback for any keyboard input.

        Args:
            ch: The key input character
        """
        # We have a lot of different things to match here, so
        # @pylint: disable=too-many-branches

        if ch in ["0", "1", "2", "3"]:
            # Set the active controller
            self.setActive(ord(ch) - ord("0"))
        elif ch == "i":
            # Confirm the id
            self.bc.setID()
        elif ch == "c":
            # Charge toggle
            self.bc.charge()
        elif ch == "d":
            # Discharge toggle
            self.bc.discharge()
        elif ch == "p":
            # Pause toggle
            if self.bc.state in (self.bc.S_CHARGE_PAUSE, self.bc.S_DISCHARGE_PAUSE):
                self.bc.resume()
            else:
                self.bc.pause()
        elif ch == "r":
            # Full reset if we are in Yanked state, else reset metrics
            if self.bc.state == self.bc.S_YANKED:
                self.bc.reset()
            else:
                self.bc.resetMetrics()
        elif ch == "s":
            # Toggle SoC measure state
            self.bc.socMeasureToggle()
        elif ch == "Z":
            # Simulate a charge/discharge complete state.
            if self.bc.state not in (self.bc.S_CHARGE, self.bc.S_DISCHARGE):
                self.output("Invalid state for simulating charge/discharge complete.")
            else:
                event = (
                    self.bc.E_ch_done
                    if self.bc.state == self.bc.S_CHARGE
                    else self.bc.E_dch_done
                )
                self.output("Simulating charge/discharge completed.")
                if not self.bc.transition(event):
                    self.output("ERROR Simulating charge/discharge completed.")
        elif ch in ("o", " "):
            # Toggle output pause
            self.pause = not self.pause

            if self.pause:
                self.output("Output paused...")
        else:
            self.output("Invalid input: %s", ch)

    async def statusMonitor(self):
        """
        Asyncio task to output regular BC status information to stdout.

        This task will be started automatically from `__init__` and will start
        producing output as soon as the async loop starts running.
        """
        # We do a lot of access to protected members here, so
        # @pylint: disable=protected-access

        # How long to delay between updates
        update_delay = 500
        # How often to print a header
        header_interval = 10
        # Counter to when next to print a header
        header_cnt = 0

        # Max width for the state name
        st_w = max(len(n) for n in self.bc.STATE_NAME)

        # The header
        # NOTE: Line draw characters are Unicode points from here:
        #       https://en.wikipedia.org/wiki/Box-drawing_characters
        header = (
            f"┃ Name ┃ {'State':<{st_w}} | {'ID':<10} "
            + "┃  V mV | V SampT "
            + "┃ S | P | Ch mA | Ch mAh | Ch Tm | C SampT "
            + "┃ S | P | Dch mA | Dch mAh | Dch Tm | D SampT "
            + "┃ SoC State | SoC Cycle | SoC Time "
            + "┃"
        )

        # We run all the time
        while True:
            await asyncio.sleep_ms(update_delay)

            if self.pause:
                continue

            if header_cnt == 0:
                self.output("\x1B[4m" + header + "\x1B[0m")
                header_cnt = header_interval

            header_cnt -= 1

            ch_vals = self.bc.charge_vals
            dch_vals = self.bc.discharge_vals

            soc_cycle = f"{self.bc.soc_m.cycle}/{self.bc.soc_m.cycles}"
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

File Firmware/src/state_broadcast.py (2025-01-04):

"""
Battery status and progress broadcasting module.

This module provides support for monitoring one or more `BatteryController`
instances and publishing regular progress messages via MQTT_ from the
`broadcast` async task..

It is also responsible for connecting to the network, and MQTT_ server, and for
monitoring this connection. If the connection to the WiFi or MQTT_ server drops,
the `MQTTClient` will automatically try to reconnect.

It also has the basic framework in place for receiving commands via MQTT_ should
this be needed in future.

It uses **Peter Hinch's** `Asynchronous MQTT`_ module which also handles the
WiFi connection as mentioned above.

The MQTT server and connection details are contained in the `net_conf`, and it's
site local config, module.

.. _MQTT: https://en.wikipedia.org/wiki/MQTT
.. _`Asynchronous MQTT`: https://github.com/peterhinch/micropython-mqtt
"""

import json
import ntptime
import uasyncio as asyncio
from lib import ulogging as logging
from lib.mqtt_as import MQTTClient, config
from lib.bat_controller import BatteryController
import net_conf


async def clientUp(client):
    """
    Task to monitor for when the client comes up.

    Once the client is up, we set the time from the network and also subscribe
    to any topics we need to.
    """

    while True:
        # Wait on an Event
        await client.up.wait()
        # We need to clear the event to signal that we noticed it.
        client.up.clear()

        logging.info("Network: Connection is up.")

        # Subscribe to any topics defined
        await client.subscribe(net_conf.MQTT_CTL_TOPIC, 0)

        # Sync network time
        try:
            # We use the default `pool.ntp.org` time servers for the time.
            ntptime.settime()
            logging.info("Network: Time synced to pool.ntp.org.")
        except Exception as exc:
            logging.error("Network: Error syncing time: %s", exc)


async def clientDown(client):
    """
    Task to monitor for when the client connection goes down.

    This only logs a message. The client will auto try to reconnect.
    """
    while True:
        # Pause until outage
        await client.down.wait()
        # We need to clear the event to signal that we noticed it.
        client.down.clear()

        logging.error(
            "Network: WiFi or broker is down. Auto reconnect will be attempted."
        )


async def messages(client):
    """
    Manage control messages received via MQTT.
    """
    async for topic, msg, retained in client.queue:
        logging.info("MQTT CTL: %s, %s, %s", topic.decode(), msg.decode(), retained)


def buildMsg(bc: BatteryController) -> dict:
    """
    Builds the MQTT message based on the status of the supplied BC.

    Args:
        bc: A Battery controller instance.
    """

    msg = {"state": bc.state_name}

    if bc.state == bc.S_DISABLED:
        # Nothing more for disabled.
        return msg

    # Add the battery ID if we have it.
    if bc.bat_id:
        msg["bat_id"] = bc.bat_id

    if bc.state not in [
        bc.S_BAT_ID,
        bc.S_CHARGE,
        bc.S_DISCHARGE,
        bc.S_CHARGED,
        bc.S_DISCHARGED,
    ]:
        # Any state other than the above we do not have anything else to add.
        return msg

    # Always add the battery voltage
    msg["bat_v"] = bc.bat_v

    # Nothing more for only battery with id
    if bc.state == bc.S_BAT_ID:
        return msg

    # We are charging or discharging. Add the correct charge monitor details.
    # @pylint: disable=protected-access
    mon = bc._ch_mon if bc.state in (bc.S_CHARGE, bc.S_CHARGED) else bc._dch_mon

    msg["adc_v"] = mon.voltage
    msg["current"] = mon.current
    msg["charge"] = mon.charge
    msg["mAh"] = mon.mAh
    msg["tm"] = round(mon.charge_time / 1000)
    msg["shunt"] = mon._shunt

    return msg


async def broadcast(bcs: list[BatteryController,]):
    """
    Monitors each `BatteryController` in the ``bcs`` list and broadcasts MQTT
    messages on status changes and charge/discharge progress.

    In addition to monitoring the BCs, this task also sets up the `MQTTClient`
    and by extension the WiFi connection, and also connects to the network.

    Warning:
        Docs needs to be completed...
    """

    # We need access to some protected members of the BatteryController class,
    # so @pylint: disable=protected-access

    # Network configuration using mqtt_as config structure
    config["ssid"] = net_conf.SSID
    config["wifi_pw"] = net_conf.PASS
    config["server"] = net_conf.MQTT_HOST
    config["queue_len"] = 1  # Use event interface with default queue size
    MQTTClient.DEBUG = net_conf.MQTT_DEBUG  # Optional: print diagnostic messages

    # Create an MQTTClient instance and wait for it to connect.
    client = MQTTClient(config)
    await client.connect()

    # While we wait, we start the event tasks.
    for task in (clientUp, clientDown, messages):
        asyncio.create_task(task(client))

    stats = {bc.name: {"state": None} for bc in bcs}

    while True:
        for bc in bcs:
            await asyncio.sleep_ms(250)

            st = stats[bc.name]
            topic = msg = None

            if st["state"] != bc.state or bc.state in [
                bc.S_BAT_ID,
                bc.S_CHARGE,
                bc.S_DISCHARGE,
            ]:
                st["state"] = bc.state
                topic = f"{net_conf.MQTT_PUB_TOPIC}/{bc.name}"
                msg = buildMsg(bc)

            if msg:
                await client.publish(topic, json.dumps(msg), qos=0)

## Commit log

2024-10-05 Add initial Schematic and PCB layout
    [BatCapMeter.kicad_pcb, BatCapMeter.kicad_sch]
2024-10-13 Add new Charge Controller
2024-10-13 Add ADC access and tracking to Charge Controller
2024-11-03 Charge controller features update
2024-11-16 BCMView: Battery ID - 2
2024-11-24 BMCView to start Charge/Discharge
2024-12-01 BCMView: Show charge and discharge progress
2024-12-28 Change to managing by State Machine
    [BatCapMeter.kicad_sch]
2025-01-04 Release v0.5.0
    [BatCapMeter.kicad_pcb, BatCapMeter.kicad_sch]
2025-02-28 Only publish Battery+ID messages on bat_v change
    Closes #41
2025-03-02 Use bat voltage on startup instead of 0V
2025-03-02 * First commit for calibration
    - Add a Calibration menu under config
    - Add A Calibration screen to manage initial calibration sans saving.
2025-03-02 * Fix sitelocal_conf.updateLocal
    - The micropython version of `str.split` does not support a `maxsplit`
    arg.
    [sitelocal_conf.py]
2025-03-02 * Make the current monitor shut resistors calibrateable.
    - Add the new shunt config with support for site local configs
    - Update the main config to use this shunt config to set up the BC
    hardware.
    - Add functionality to the calibration screen to save site local shunt
    values per BC
2025-04-21 Update PCB Toner gen Makefile
    * Add option to generate an SMD placement pdf
2025-04-21 Update PCB to v1.1.0
    * Add a switch for a 5V fan on the controll PCB
    * Add a dischrage LED
    [BatCapMeter.kicad_pcb, BatCapMeter.kicad_sch]
2025-04-26 Add toner transfer PCB images
2025-04-27 Prep for release v0.7.0
    [BatCapMeter.kicad_pcb, BatCapMeter.kicad_sch]
2025-04-28 Update Toner Transfer PCB Layout
2025-04-28 More PCB layout updates.
2025-05-04 Add a calibration jumper
    [BatCapMeter.kicad_pcb, BatCapMeter.kicad_sch]
2025-05-11 Remove old ADC tracker code
2025-05-11 Add a new config environment for the MCU device
2025-05-11 Makefile updates and cleanup
    * Add targets to download the correct Micropython binary as defined in
    MCU_CONF if not available.
    * Flash binary will now only flash for ESP32 and auto downloads the bin
    * Lots of cleanup in the Makefile
    Closes #50
2025-05-11 Release v0.8.0
    [BatCapMeter.kicad_pcb, BatCapMeter.kicad_sch]
2025-05-17 Update and rename schematic image
2025-07-11 Small Fixes and Updates
    [BatCapMeter.kicad_sch]
2025-07-11 Prep for Release 0.9.0
    [BatCapMeter.kicad_sch]
2025-07-12 Detect charged state when charge current falls to zero.
2025-09-26 Fix issues with large current drops on start charge
2025-09-27 Add watchdog timer to guard against code freezes
2025-11-09 Switch to UI submodule
    * Add the UI lib as a new submodule
    * Switch all libs and packages to use this new submodule
